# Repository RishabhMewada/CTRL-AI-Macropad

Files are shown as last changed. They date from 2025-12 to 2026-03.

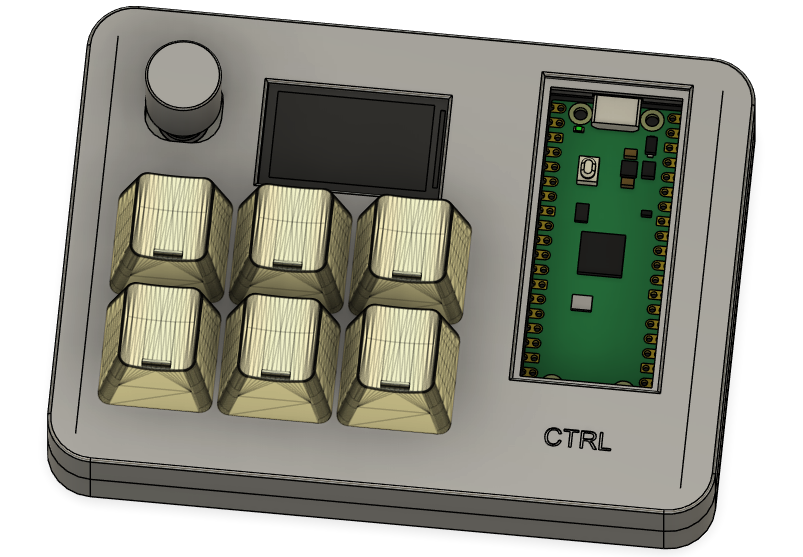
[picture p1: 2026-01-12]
Images/assembled-case.png

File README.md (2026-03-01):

# CTRL-AI-Macropad


## What is CTRL?
CTRL is a custom-built Human-Computer Interaction (HCI) Development Board designed for productivity tooling, embedded experimentation, wireless HID systems, and future AI-assisted workflows.

Originally developed as a programmable macropad, the project has evolved into a battery-powered, dual-transport embedded platform built around the Raspberry Pi Pico (RP2040), featuring modular firmware architecture and wireless expansion capabilities.CTRL is a custom-built Human-Computer Interaction (HCI) Development Board designed for productivity tooling, embedded experimentation, wireless HID systems, and future AI-assisted workflows.

Originally developed as a programmable macropad, the project has evolved into a battery-powered, dual-transport embedded platform built around the Raspberry Pi Pico (RP2040), featuring modular firmware architecture and wireless expansion capabilities.
<p align="center">
  

-------------------------------------------------------------------------------------------------
## Purpose 
The goal of this project was to design a fully custom embedded input system from scratch — including:

- PCB design
- Multi-MCU system architecture
- Power management circuitry
- Firmware modularization
- Custom enclosure
- This project focuses on understanding:
- Embedded system design
- Hardware-software co-design
- Power-aware firmware
- Multi-transport communication (USB + BLE)
- Expandable interaction hardware

The system is built with future extensibility in mind rather than being limited to fixed macro execution.

 <p align="center">
  
</p>

-------------------------------------------------------------------------------------------------
## Features

*Core Hardware*

- 6 Mechanical Keys (Cherry MX compatible)
- Rotary Encoder with integrated push switch
- 1.14″ IPS SPI Display (ST7789)
- Raspberry Pi Pico (RP2040)
- BLE Co-Processor (UART interface)
- Li-ion battery support
- On-board charging IC
- Software-controlled power system
- Fully custom 2-layer PCB
- Expansion GPIO header
- SWD debug header
-------------------------------------------------------------------------------------------------
## Transport & Connectivity

- USB HID (via Raspberry Pi Pico)
- Bluetooth HID (via BLE co-processor)
- UART-based inter-MCU communication
- I²C sensor bus (IMU connected with interrupt support)
-------------------------------------------------------------------------------------------------
## Hardware
The PCB is designed using KiCad (open-source) and Fusion 360.

Specifications

- 2-layer PCB
- Diode-protected key matrix
- SPI-connected IPS display
- I²C IMU (interrupt-driven)
- UART-connected BLE module
- Li-ion battery charging circuit (MCP73831)
- 3.3V LDO regulator (AP2112K)
- Single USB-C interface (handled by Pico only)

All PCB source files are available in `/hardware/kicad`.

<p align="center">
  
</p>

-------------------------------------------------------------------------------------------------

## Firmware
The firmware architecture has evolved from a monolithic USB HID mapping into a modular embedded system design.

**Architecture Overview**

*Subsystems include:*

- Input Processing Layer
- Power Management Layer
- Transport Abstraction Layer
- Communication Layer (UART BLE)
- Mode Manager

*Supported Features*

- Key matrix scanning
- Rotary encoder quadrature decoding
- USB HID output
- Bluetooth HID output
- 5-second long-press soft power
- Battery voltage monitoring
- Event-driven input routing

*Planned Enhancements*

- Dynamic key remapping
- On-device UI configuration
- BLE protocol expansion
- IMU gesture-based input
- Power optimization (sleep states)
- Desktop companion software

Firmware files are located in `/firmware`.

-------------------------------------------------------------------------------------------------
## Case
The enclosure is designed in Fusion 360 (personal use).
[STEP and source files are included in `/case`.]

**Dimensions:**
- Length: 11.8 cm
- Height: 6.3 cm
- Thickness: 1.5 cm

The enclosure is designed to be 3D printed.

~ **Recommended filament:** PLA  
PLA provides good dimensional accuracy, clean surface finish, and is easy to print, making it ideal for prototyping and desktop devices.

~ **Alternative:** PETG  
PETG can be used for improved durability and heat resistance, though it may require tuning for small cutouts.

[The enclosure is intended for indoor use and does not require high-temperature or impact-resistant materials.]

<p align="center">
  
</p>

-------------------------------------------------------------------------------------------------
## Images




-------------------------------------------------------------------------------------------------

## Future AI Integration (Planned)
CTRL is designed to support AI-assisted workflows through a host-based companion application.
AI processing will run on the host computer, while CTRL serves as:

~ low-latency physical interface
~ status display device
~ context-aware shortcut controller

The hardware architecture is transport-agnostic, enabling flexible integration with higher-level software systems.

-------------------------------------------------------------------------------------------------
## BOM
The complete bill of materials (BOM), including purchase links, is available in  
`/hardware/bom.csv`.

Manufacturing & sourcing:
- PCB fabrication: **JLCPCB**
- Components (India): **Robu.in**
- Enclosure: Online 3D printing services
  
-------------------------------------------------------------------------------------------------
## License
This project is open-source hardware and software and is released under the **MIT License**.

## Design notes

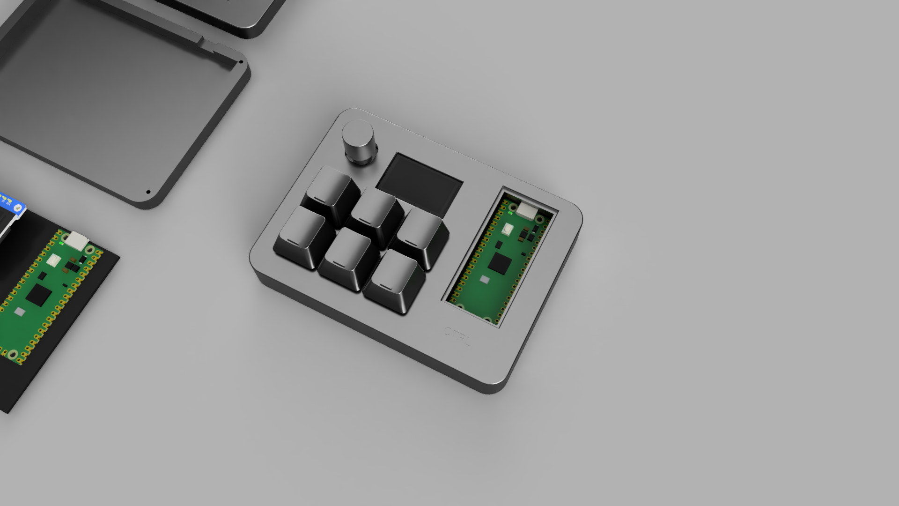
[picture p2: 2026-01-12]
Images/CTRL-AI-Macropad.f3d_2025-Dec-31_07-07-15PM-000_CustomizedView15149174459.png

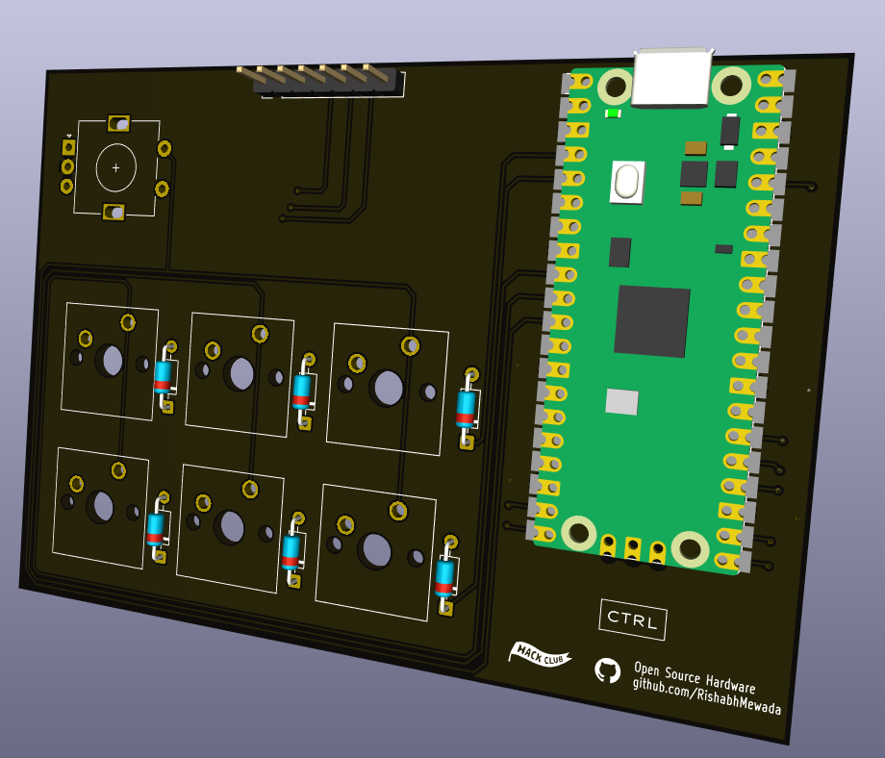
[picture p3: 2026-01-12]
Images/pcb-3d.png

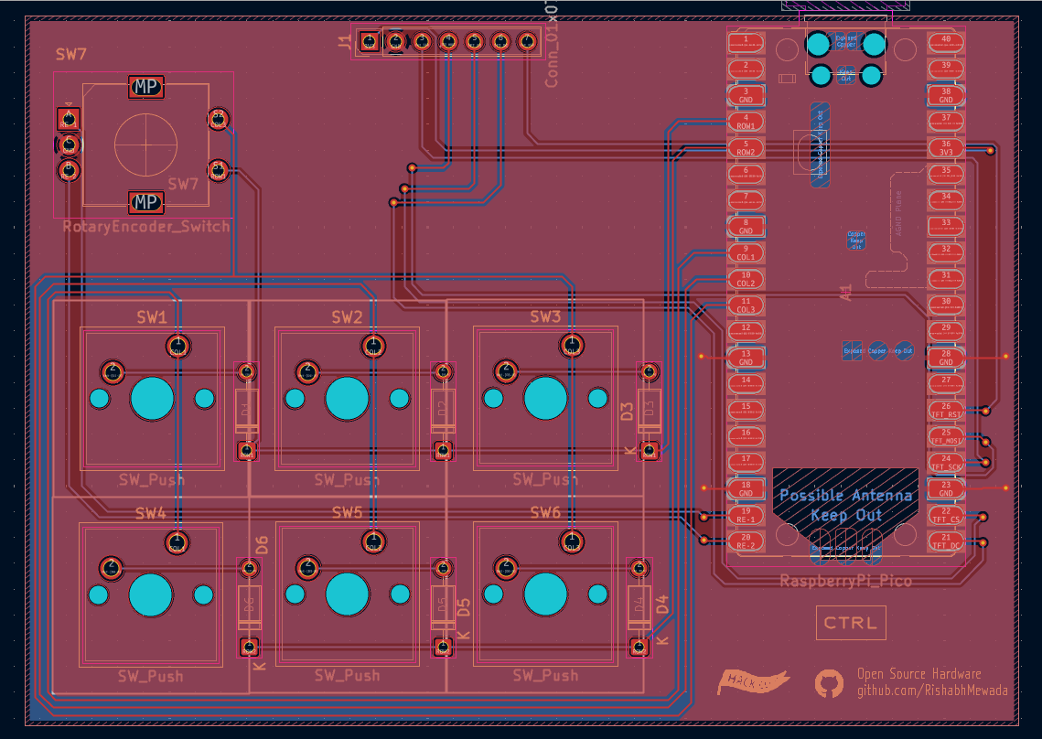
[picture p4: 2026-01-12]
Images/Pcb.png

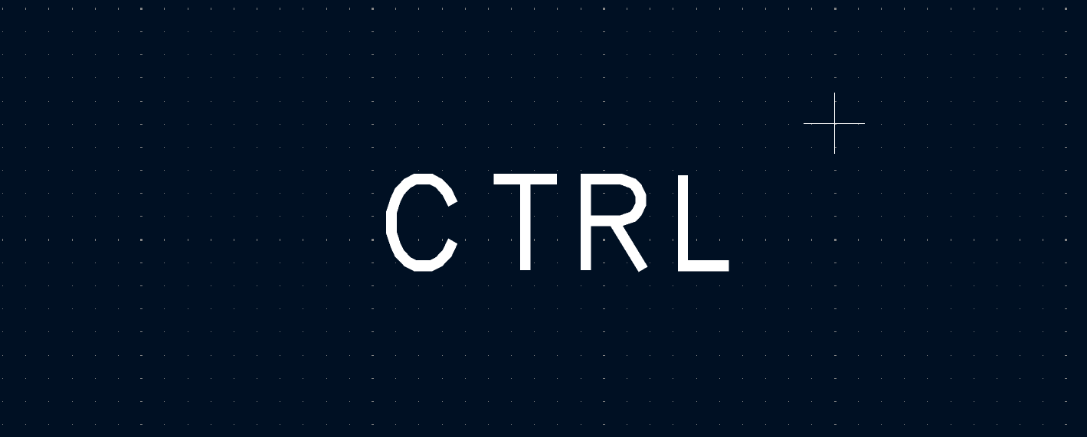
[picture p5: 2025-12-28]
Images/logo.png

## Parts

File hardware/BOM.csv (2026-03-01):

Item | Reference | Quantity | Part Name | Specification / Notes | Supplier | Link
1 | U1 | 1 | Raspberry Pi Pico (RP2040) | Microcontroller board | Robu.in | https://robu.in/product/raspberry-pi-pico/
2 | SW1-SW6 | 6 | Mechanical Key Switch | Cherry MX compatible (MX style) | Mckeys | https://meckeys.com/shop/accessories/keyboard-accessories/key-switches/cherry-mx-rgb-switch/
3 | D1-D7 | 7 | Signal Diode | 1N4148 DO-35 through-hole | Element14 india | https://in.element14.com/multicomp-pro/1n4148-do-35/small-signal-sw-diode-100v-do/dp/2675146
4 | SW7 | 1 | Rotary Encoder with Push Button | EC11 / EC12 style encoder | Flyrobo.in | https://www.flyrobo.in/ec11-rotary-encoder-with-switch-digital-potentiometer-20mm
5 | DS1 | 1 | IPS TFT Display | 1.14 inch 135x240 SPI IPS TFT | zbotic.in | https://zbotic.in/product/1-14-inch-135240-rgb-tft-ips-lcd-module-8pin-st7789-chip/
6 | J1 | 1 | Pin Header | 1x7 2.54mm Through-Hole | Amazon.in | https://www.amazon.in/7%C3%971-7Pin-Square-Straight-Header-Connector/dp/B0FFHLJHGR
7 | U2 | 1 | Bluetooth Module | MDBT50Q-1MV2 | Mouser Electronics | https://www.mouser.in/ProductDetail/Seeed-Studio/113990584?qs=0lSvoLzn4L92aqwOsif%2FOw%3D%3D
8 | BT1 | 1 | Li-Po Battery | 3.7 V Li-Po, 500–1000 mAh | Robu.in | https://robu.in/product/1500mah-pcm-protected-micro-li-po-battery/
9 | U3 | 1 | Battery Charging IC | MCP73831-2-OT (Li-Po charger) | Robu.in | https://robu.in/product/mcp73831t-2aci-ot-4-2v-500ma-single-cell-li-ion-li-polymer-battery-charge-management-controller-5-pin-sot-23-microchip-technology/
10 | J2 | 1 | Battery Connector | JST-PH 2-pin, 2.0 mm | Sunrom electronics | https://www.sunrom.com/p/2-pin-jst-ph-20mm-both-side-female-30cm
11 | J3 | 1 | External connector | 1×8 SWD Header, 2.54 mm | Amazon.in | https://www.amazon.in/8%C3%971-8Pin-Right-Angle-Header-Connector/dp/B0FFHNVV9Y
12 | U4 | 1 | MPU | MPU-6050 | Quartz components | https://quartzcomponents.com/products/mpu-6050-3-axis-gyro-accelerometer-ic-tdk-invensense-qfn-24-smd-package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
13 | PCB | 1 | Custom PCB | 2-layer PCB (KiCad) | JLCPCB | https://jlcpcb.com/
14 | CASE | 1 | 3D Printed Enclosure | Fusion 360 designed case | Local / Online 3D Print Service | N/A
15 | H1 | 1 | Header | 2 pin JST PH 2.0mm SMT Header Horizontal Right Angle Side Entry | Sunrom electronics | https://www.sunrom.com/p/2-pin-jst-ph-20mm-smt-header-horizontal-right-angle-side-entry
16 | U5 | 1 | Battery charger IC | AP2112K-3.3

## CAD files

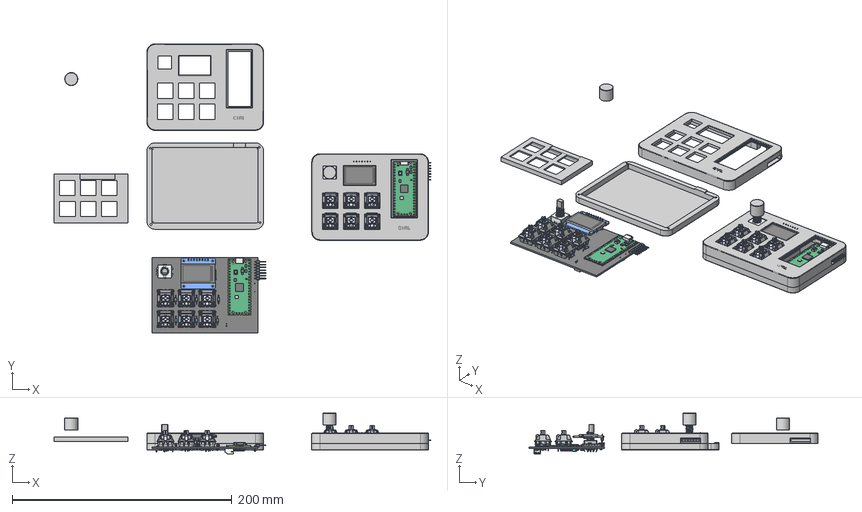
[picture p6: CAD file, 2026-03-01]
case/CTRL-AI-Macropad.f3d.step
343.0 x 263.2 x 37.2 mm
MX Öá °´¼ü¡ä_¨¹ ___¡§1 x 12
MX Öá ÖáÌå¨¢¨¬ _¡§¡é¡§__ x 12
MXÖá ÎÞÃ±LEDLEDLED x 12
MXÖá ÖáÌå µ×²¿ ¦Ì¡ Á2__Ä¬ÈÏ_¨¢2____¨¨_ x 12
Õë½Å___Ä¬ÈÏ__¨¨ _ x 12
Ðý×ª±àÂëÆ÷ x 2
no_8logo x 2
no_8logo--1 x 2
no_8logo--2 x 2
no_8logo--3 x 2
no_8logo--4 x 2
no_8logo--5 x 2
no_8logo--6 x 2
no_8logo--7 x 2
no_8logo--8 x 2
no_8logo--9 x 2
no_8logo--10 x 2
no_8logo--11 x 2
no_8logo--12 x 2
no_8logo--13 x 2
no_8logo--14 x 2
no_8logo--15 x 2
no_8logo--16 x 2
no_8logo--17 x 2
no_8logo--18 x 2
no_8logo--19 x 2
no_8logo--20 x 2
no_8logo--21 x 2
no_8logo--22 x 2
no_8logo--23 x 2
no_8logo--24 x 2
no_8logo--25 x 2
no_8logo--26 x 2
no_8logo--27 x 2
no_8logo--28 x 2
no_8logo--29 x 2
no_8logo--30 x 2
ER-TFT1.14-1 x 2
±³Ãæ x 2
Pin Header 8P x 2
Pin Header 8P--1 x 2
Pin Header 8P--2 x 2
Pin Header 8P--3 x 2
Pin Header 8P--4 x 2
Pin Header 8P--5 x 2
Pin Header 8P--6 x 2
Pin Header 8P--7 x 2
PCB°å x 2
D_DO-35_SOD27_P7.62mm_Horizontal x 14
PinHeader_1x07_P2.54mm_Vertical x 2
RaspberryPi_Pico_Module_KiCad x 2
PinHeader_1x07_P2.54mm_Horizontal x 2
SOT-23-5 x 4
Raytac_MDBT50Q x 2
JST_PH_S2B-PH-K_1x02_P2.00mm_Horizontal x 2
_autosave-Mechanical keyboard circuit_PCB x 2

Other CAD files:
case/CTRL-AI-Macropad.f3d.f3z

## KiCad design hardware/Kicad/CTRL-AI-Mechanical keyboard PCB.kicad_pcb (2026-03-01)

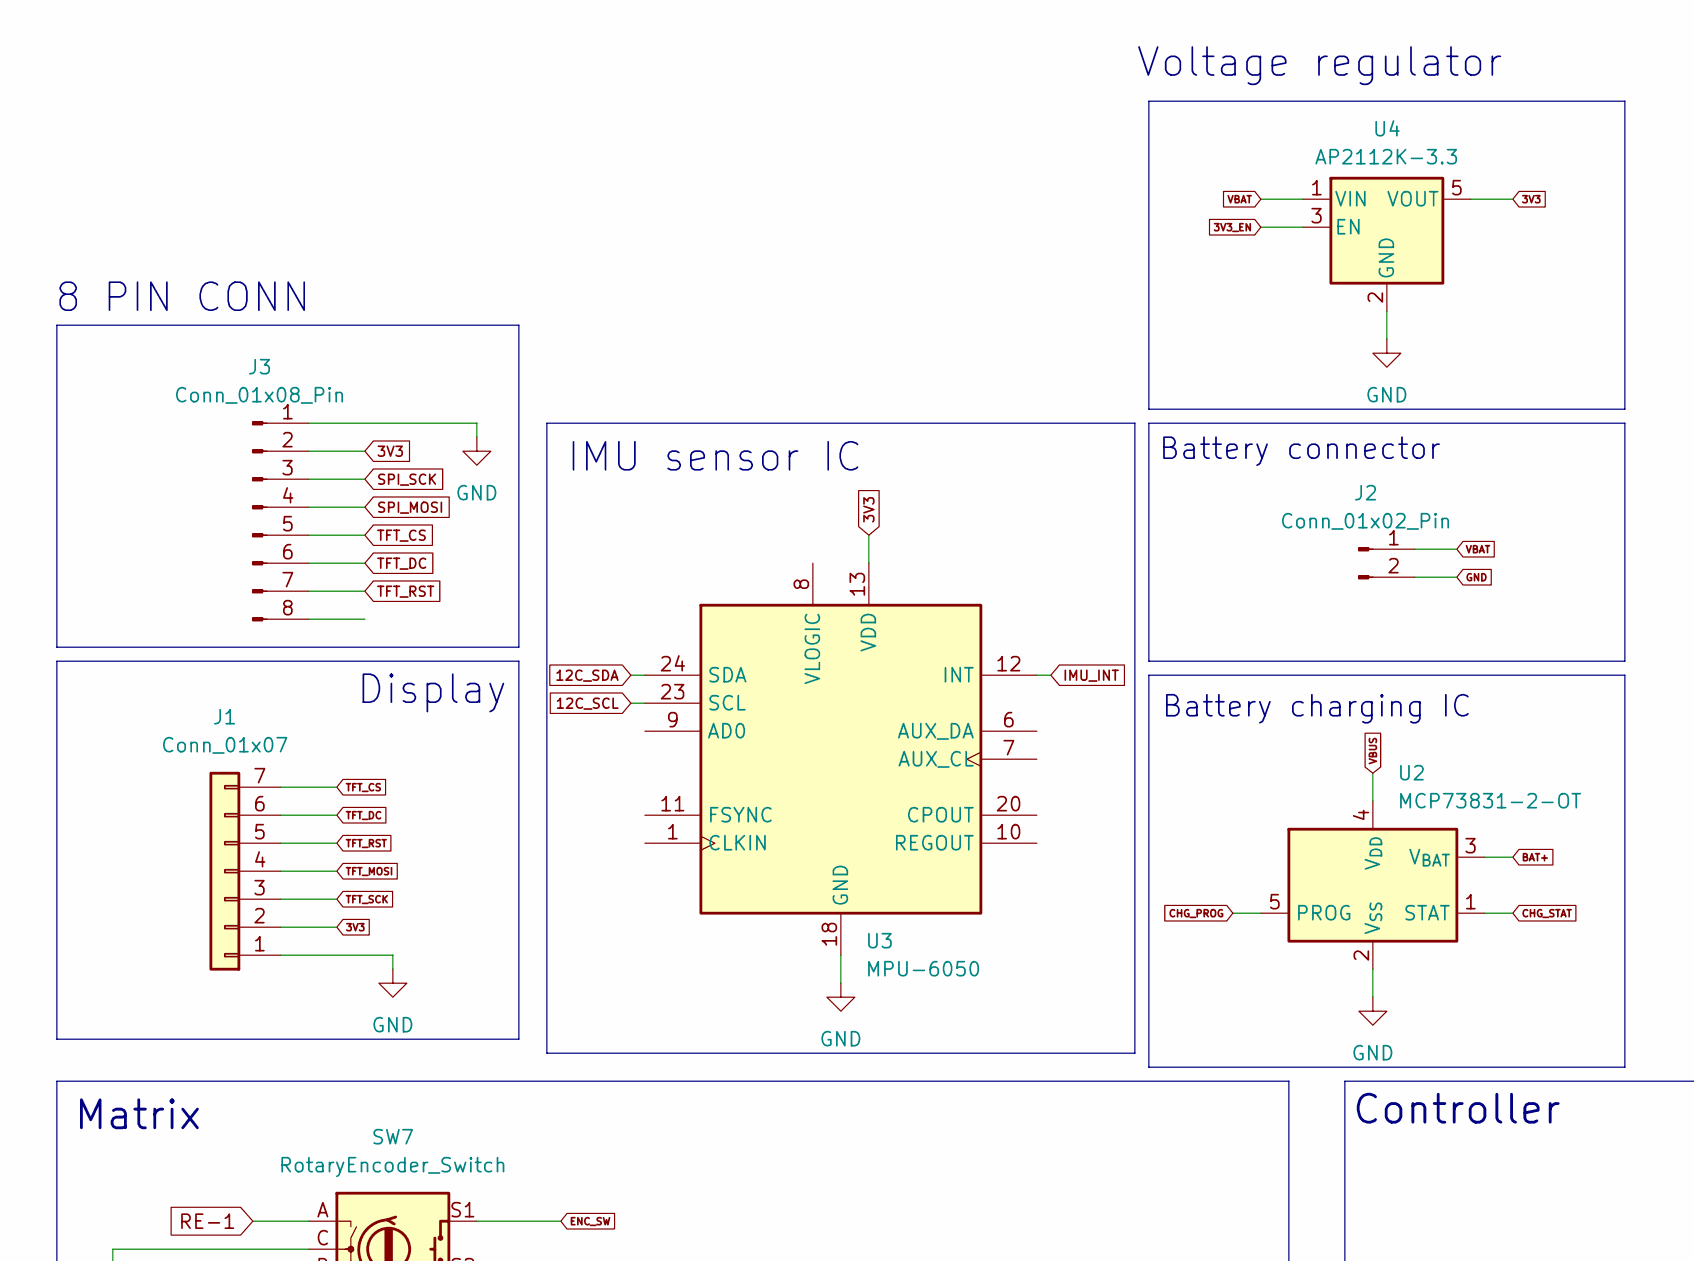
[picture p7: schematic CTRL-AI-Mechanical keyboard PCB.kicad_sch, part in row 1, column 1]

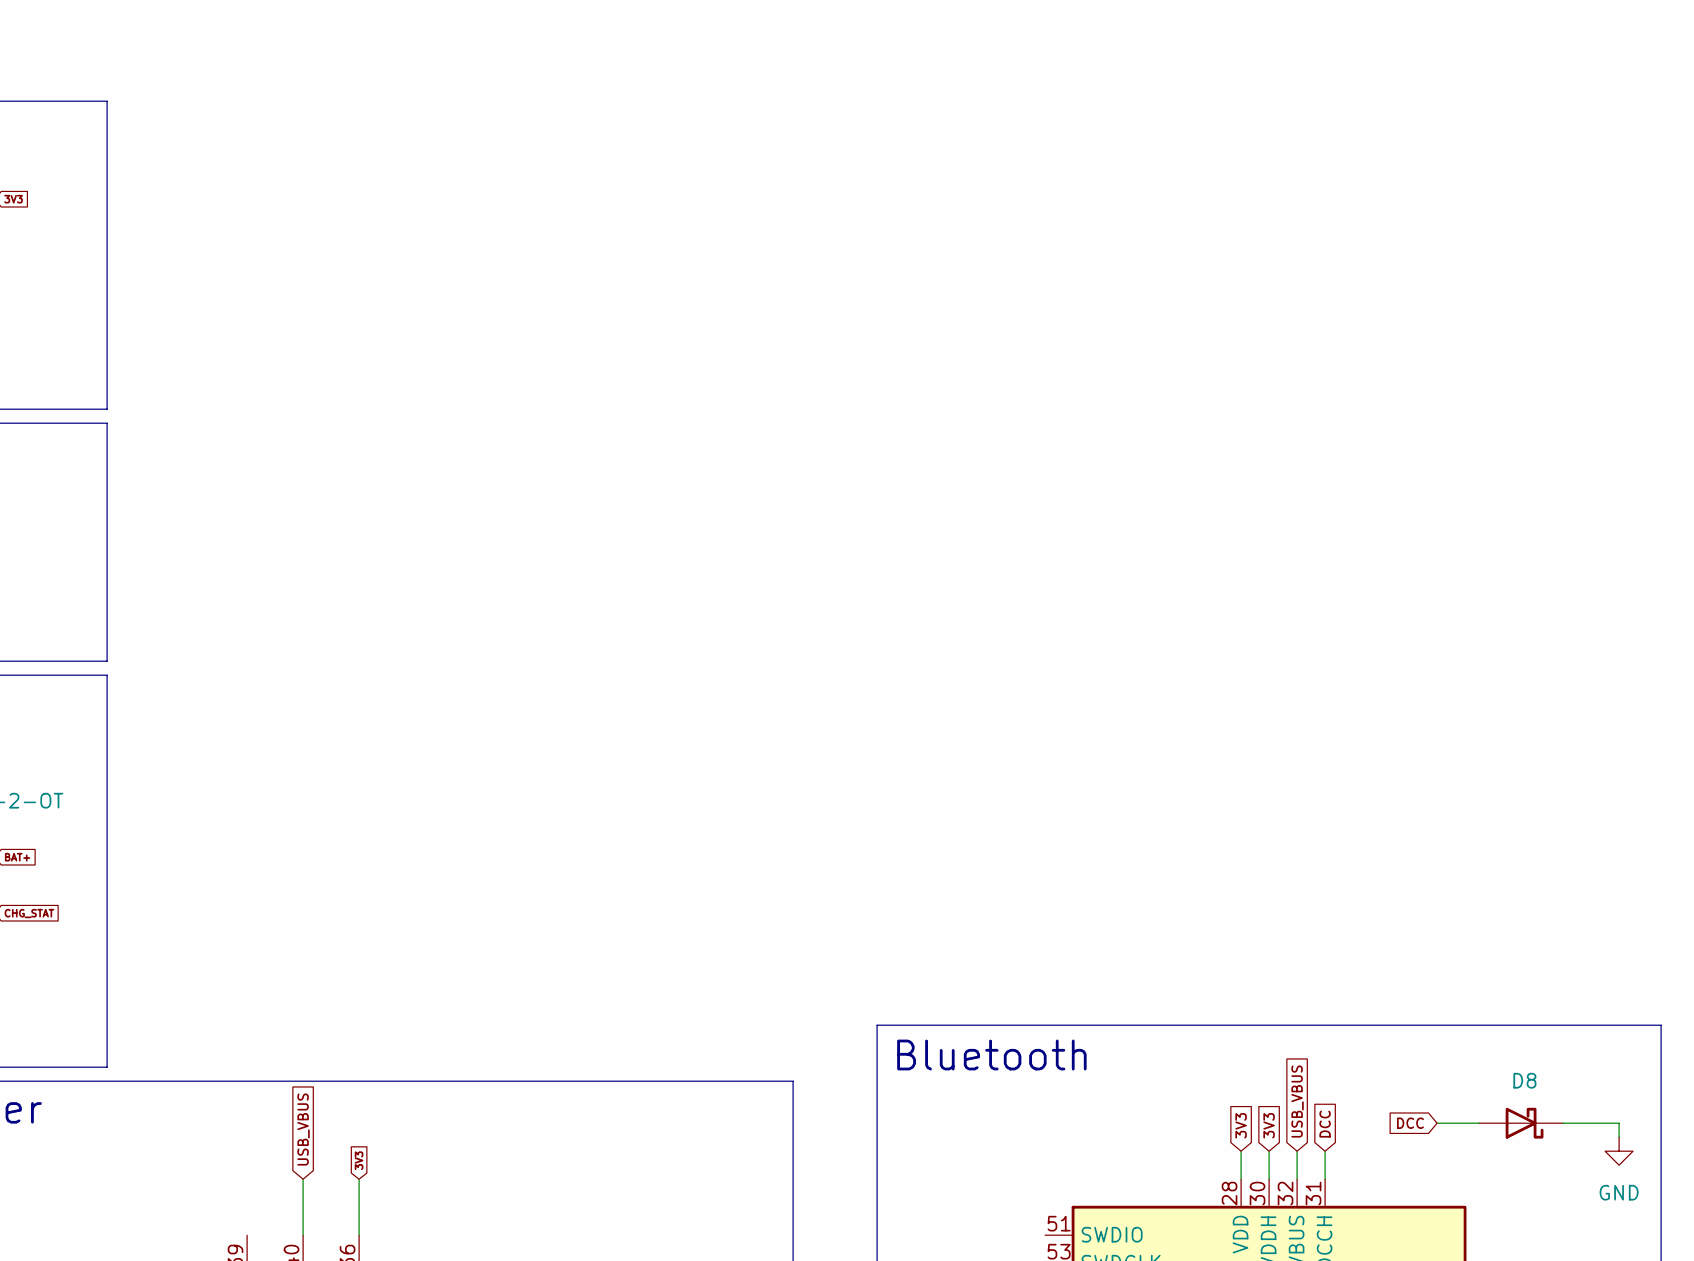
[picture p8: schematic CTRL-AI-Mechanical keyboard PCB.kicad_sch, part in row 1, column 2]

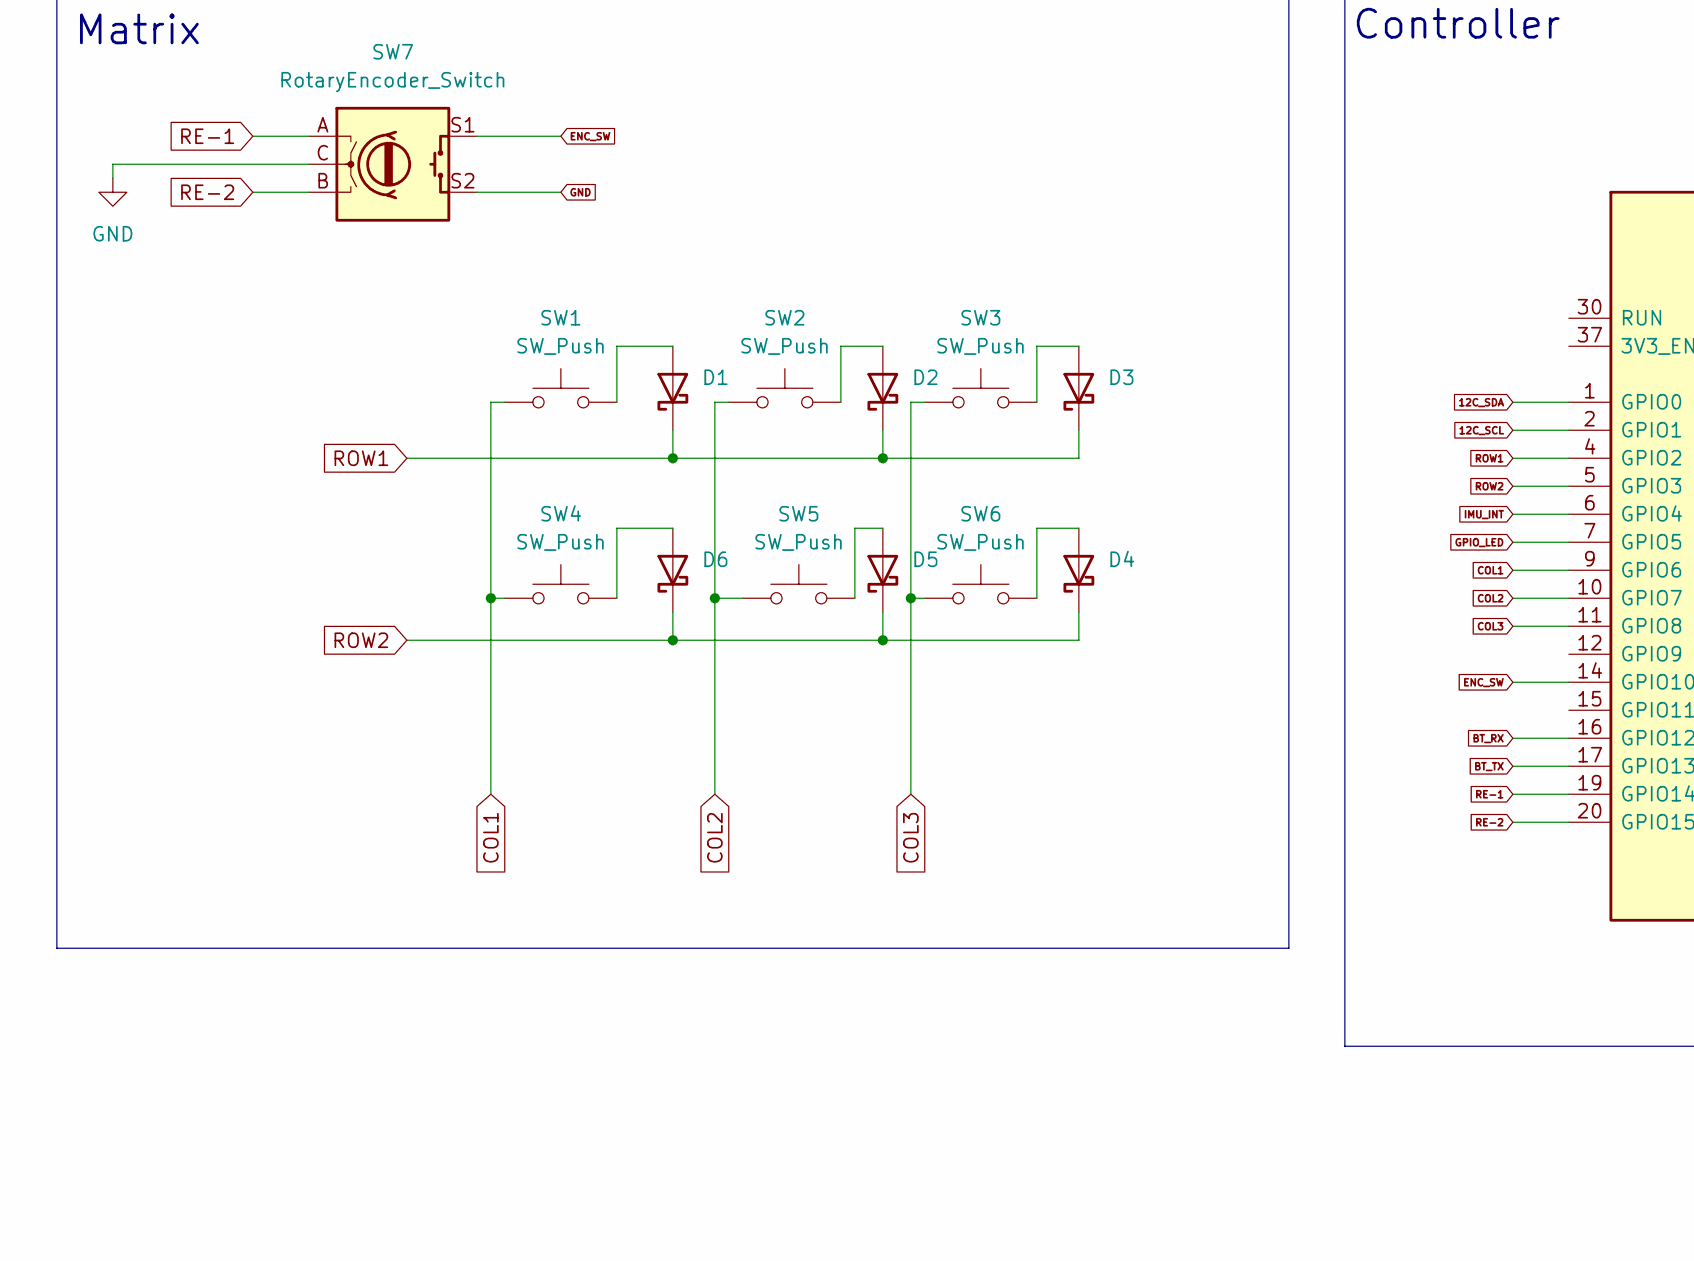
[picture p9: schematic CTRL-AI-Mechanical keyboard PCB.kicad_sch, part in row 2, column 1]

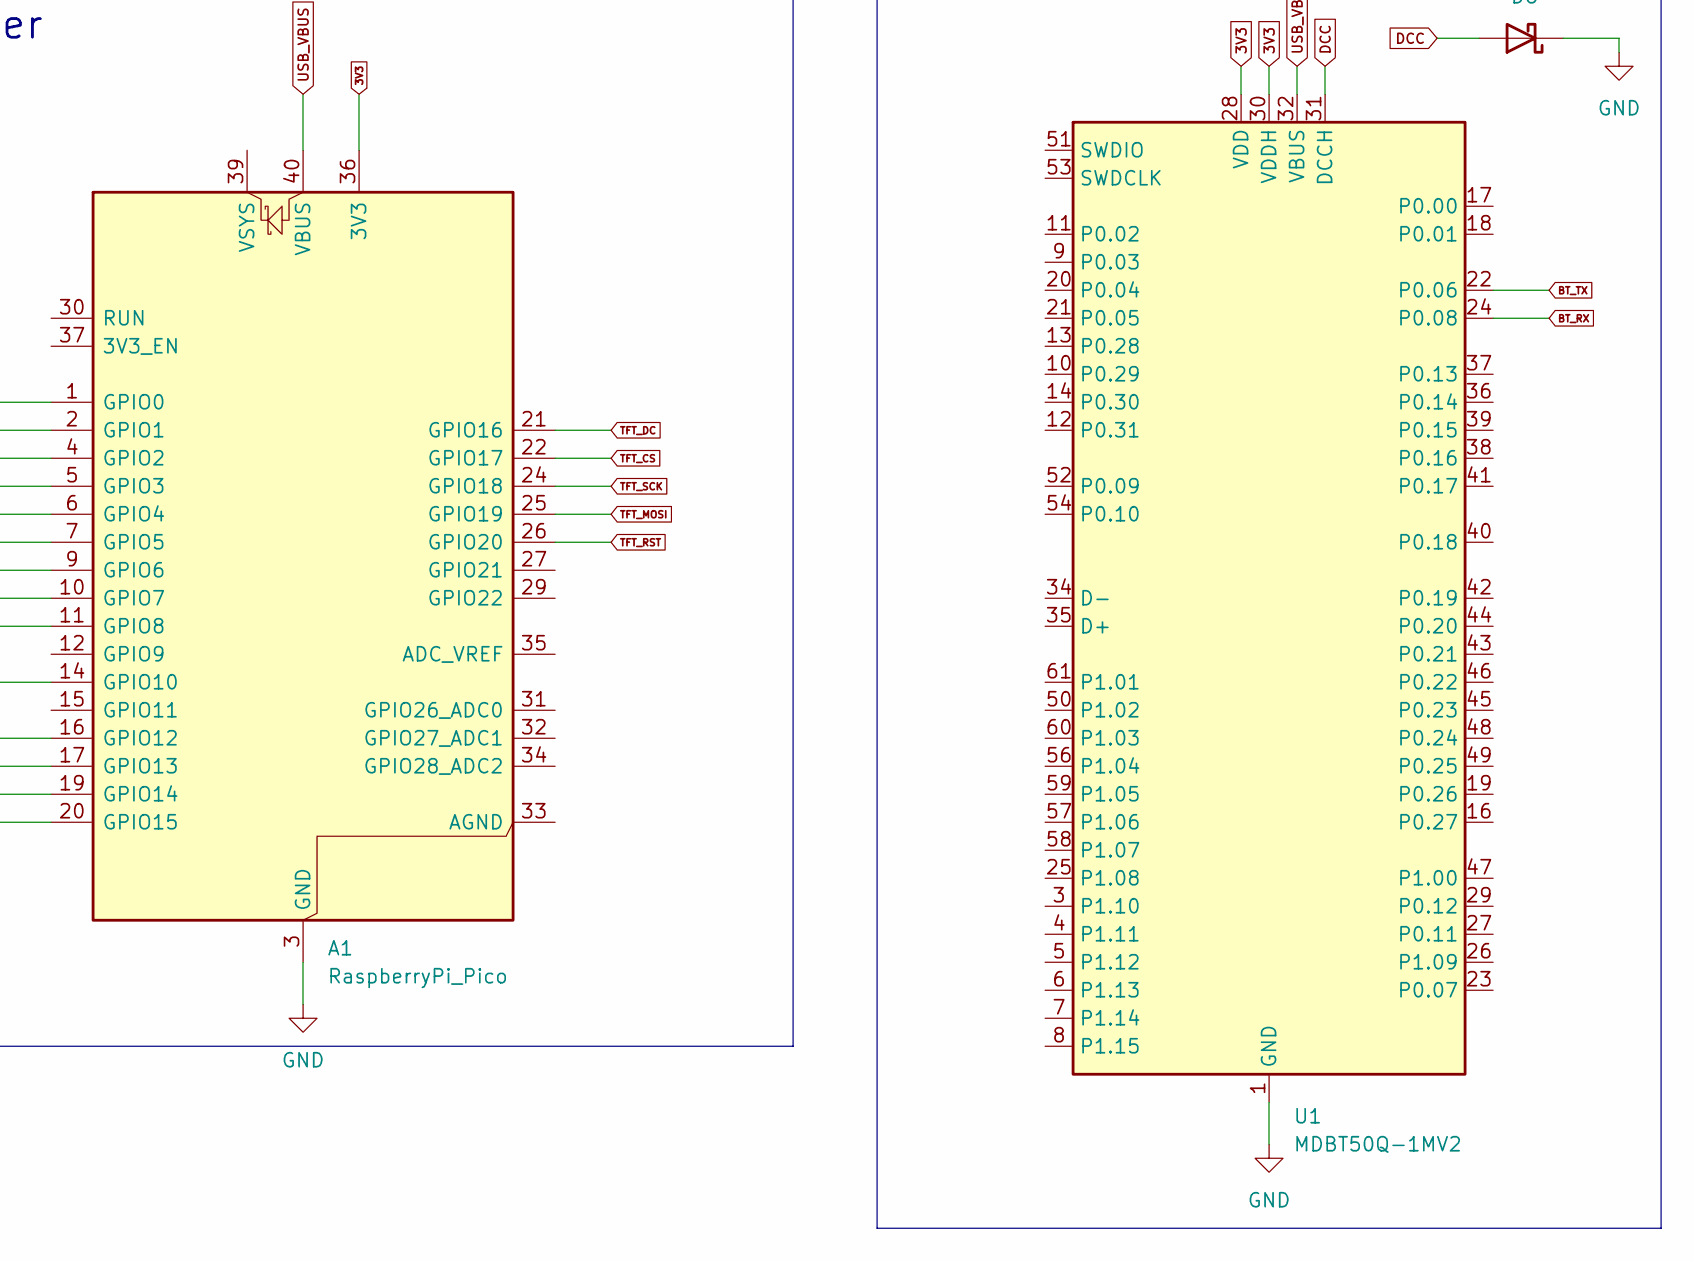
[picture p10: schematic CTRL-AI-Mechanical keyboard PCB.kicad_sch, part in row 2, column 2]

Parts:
A1: RaspberryPi_Pico; RaspberryPi_Pico_Common_Unspecified
D1, D2, D3, D4, D5, D6, D8: DSB5712; D_DO-35_SOD27_P7.62mm_Horizontal
J1: Conn_01x07; PinHeader_1x07_P2.54mm_Vertical
J2: Conn_01x02_Pin; JST_PH_S2B-PH-K_1x02_P2.00mm_Horizontal
J3: Conn_01x08_Pin; PinHeader_1x07_P2.54mm_Horizontal
SW1, SW2, SW3, SW4, SW5, SW6: SW_Push; SW_Cherry_MX_1.00u_PCB
SW7: RotaryEncoder_Switch; RotaryEncoder_Alps_EC11E-Switch_Vertical_H20mm
U1: MDBT50Q-1MV2; Raytac_MDBT50Q
U2: MCP73831-2-OT; SOT-23-5
U3: MPU-6050; InvenSense_QFN-24_4x4mm_P0.5mm
U4: AP2112K-3.3; SOT-23-5

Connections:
3V3: A1.36 (3V3), J1.2, J3.2, U1.28 (VDD), U1.30 (VDDH), U3.13 (VDD), U4.5 (VOUT)
3V3_EN: U4.3 (EN)
12C_SCL: A1.2 (GPIO1), U3.23 (SCL)
12C_SDA: A1.1 (GPIO0), U3.24 (SDA)
BAT+: U2.3 (V_{BAT})
BT_RX: A1.16 (GPIO12), U1.24 (P0.08)
BT_TX: A1.17 (GPIO13), U1.22 (P0.06)
CHG_PROG: U2.5 (PROG)
CHG_STAT: U2.1 (STAT)
COL1: A1.9 (GPIO6), SW1.1, SW4.1
COL2: A1.10 (GPIO7), SW2.1, SW5.1
COL3: A1.11 (GPIO8), SW3.1, SW6.1
DCC: D8.2 (A), U1.31 (DCCH)
ENC_SW: A1.14 (GPIO10), SW7.S1
GND: A1.3 (GND), A1.8 (GND), A1.13 (GND), A1.18 (GND), A1.23 (GND), A1.28 (GND), A1.38 (GND), D8.1 (K), J1.1, J2.2, J3.1, SW7.C, SW7.S2, U1.1 (GND), U1.2 (GND), U1.15 (GND), U1.33 (GND), U1.55 (GND), U2.2 (V_{SS}), U3.18 (GND), U4.2 (GND)
GPIO_LED: A1.7 (GPIO5)
IMU_INT: A1.6 (GPIO4), U3.12 (INT)
unnamed: D1.2 (A), SW1.2
unnamed: D2.2 (A), SW2.2
unnamed: D3.2 (A), SW3.2
unnamed: D4.2 (A), SW6.2
unnamed: D5.2 (A), SW5.2
unnamed: D6.2 (A), SW4.2
RE-1: A1.19 (GPIO14), SW7.A
RE-2: A1.20 (GPIO15), SW7.B
ROW1: A1.4 (GPIO2), D1.1 (K), D2.1 (K), D3.1 (K)
ROW2: A1.5 (GPIO3), D4.1 (K), D5.1 (K), D6.1 (K)
SPI_MOSI: J3.4
SPI_SCK: J3.3
TFT_CS: A1.22 (GPIO17), J1.7, J3.5
TFT_DC: A1.21 (GPIO16), J1.6, J3.6
TFT_MOSI: A1.25 (GPIO19), J1.4
TFT_RST: A1.26 (GPIO20), J1.5, J3.7
TFT_SCK: A1.24 (GPIO18), J1.3
USB_VBUS: A1.40 (VBUS), U1.32 (VBUS)
VBAT: J2.1, U4.1 (VIN)
VBUS: U2.4 (V_{DD})

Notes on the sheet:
Battery connector
Voltage regulator
Battery charging IC
Display
Bluetooth
Matrix
8 PIN CONN
Controller
IMU sensor IC

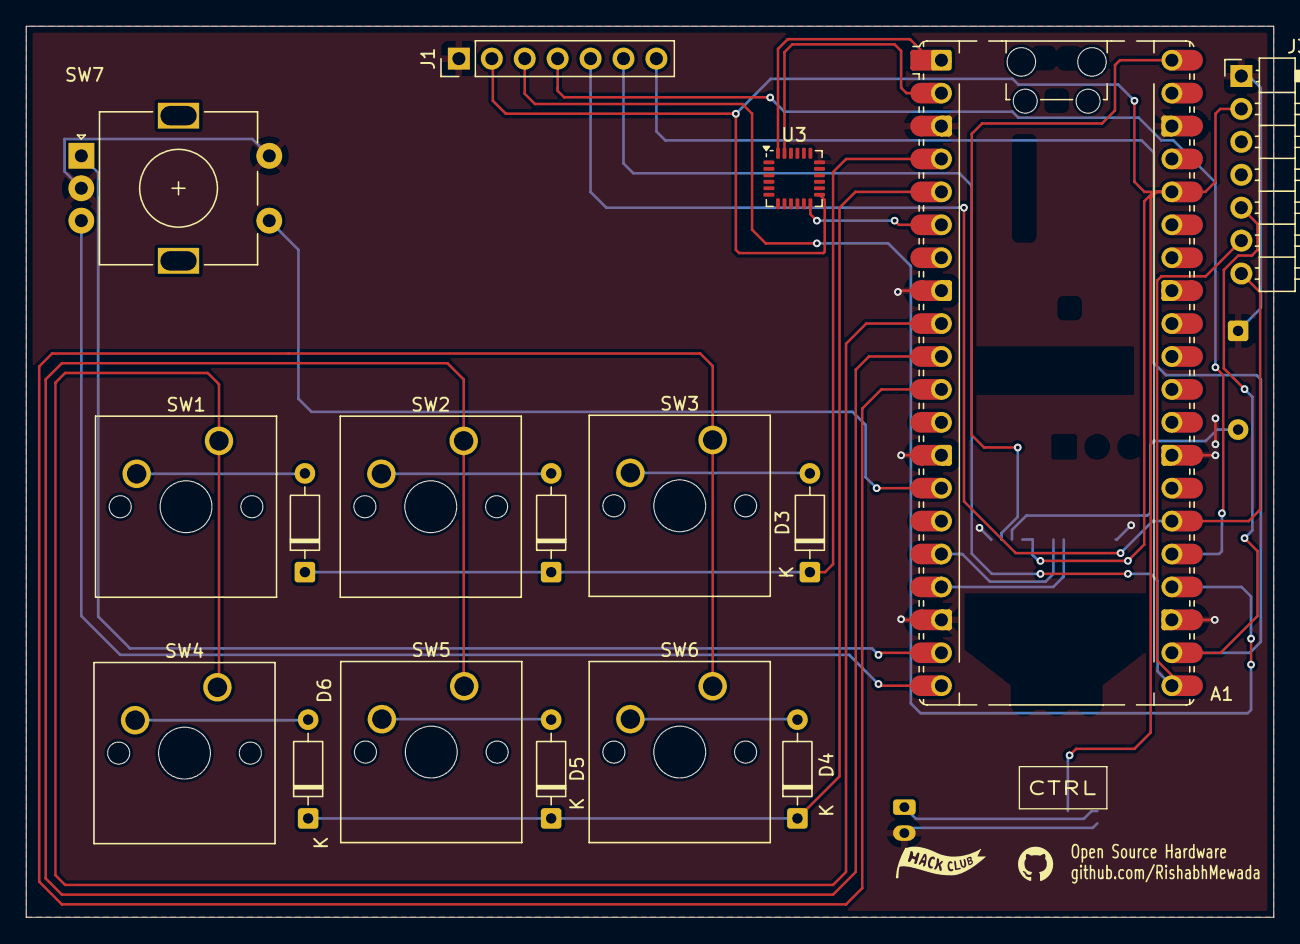
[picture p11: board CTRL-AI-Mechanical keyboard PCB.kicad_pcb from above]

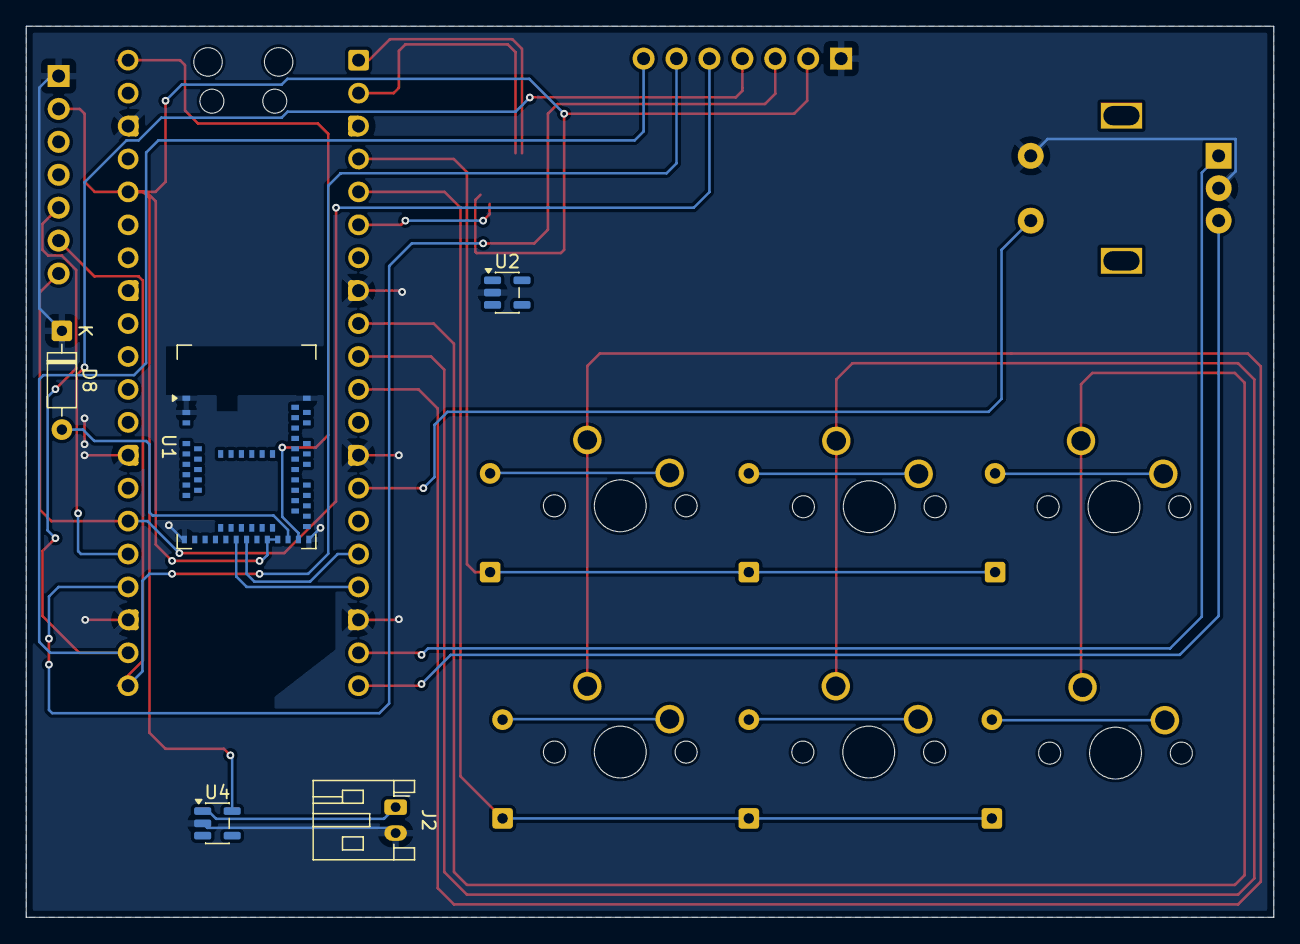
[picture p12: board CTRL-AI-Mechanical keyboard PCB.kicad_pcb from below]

Board: 2 copper layers, 96.2 x 68.8 mm, 22 parts (5 on the bottom side), 29 nets.

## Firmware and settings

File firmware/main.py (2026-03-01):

 # ================================
# CTRL Macro Pad Firmware v3.0
# AI-Ready Programmable Macro Pad
# NEW: Bluetooth, Battery Monitor, Power Management
# ================================

import board
import busio
import time
import digitalio
import analogio
from kmk.kmk_keyboard import KMKKeyboard
from kmk.scanners.keypad import MatrixScanner
from kmk.keys import KC
from kmk.modules.encoder import EncoderHandler
from kmk.modules.layers import Layers
from kmk.extensions.media_keys import MediaKeys

# ----------------
# Hardware Configuration
# ----------------
class Config:
    """Complete hardware configuration"""
    
    # Matrix Configuration (6 mechanical keys)
    ROW_PINS = (board.GP2, board.GP3)
    COL_PINS = (board.GP6, board.GP7, board.GP8)
    
    # Rotary Encoder with Push Switch
    ENCODER_A = board.GP14      # RE-1 (CLK)
    ENCODER_B = board.GP15      # RE-2 (DT)
    ENCODER_SW = board.GP14     # Switch (SW2 to GP14, SW1 to GND)
    
    # IPS Display (ST7789 - 135x240)
    DISPLAY_DC = board.GP16
    DISPLAY_CS = board.GP17
    DISPLAY_SCK = board.GP18
    DISPLAY_MOSI = board.GP19
    DISPLAY_RST = board.GP20
    
    # Battery Monitor (ADC)
    BATTERY_PIN = board.GP26    # ADC0 - Battery voltage divider
    
    # Power Management
    LONG_PRESS_MS = 5000        # 5 seconds for power toggle
    LOW_BATTERY_THRESHOLD = 3.3  # Volts
    CRITICAL_BATTERY_THRESHOLD = 3.0  # Volts
    
    # Bluetooth (Optional - if HC-05/HC-06 module added)
    # BT_TX = board.GP0  # UART TX (future expansion)
    # BT_RX = board.GP1  # UART RX (future expansion)
    
    NUM_LAYERS = 3
    DIODE_DIRECTION = "COL2ROW"

# ----------------
# Power Management System
# ----------------
class PowerManager:
    """
    Manages device power states and battery monitoring
    """
    
    def __init__(self):
        self.device_on = True
        self.battery_voltage = 0.0
        self.battery_percent = 100
        self.press_start = None
        self.in_sleep = False
        
        # Initialize battery ADC
        try:
            self.battery_adc = analogio.AnalogIn(Config.BATTERY_PIN)
            self.battery_enabled = True
            print("✓ Battery monitor enabled")
        except Exception as e:
            print(f"⚠ Battery monitor disabled: {e}")
            self.battery_enabled = False
    
    def read_battery(self):
        """Read battery voltage and calculate percentage"""
        if not self.battery_enabled:
            return 100
        
        try:
            # Read ADC value (0-65535)
            raw = self.battery_adc.value
            
            # Convert to voltage (3.3V reference, voltage divider x2)
            self.battery_voltage = (raw / 65535.0) * 3.3 * 2.0
            
            # Calculate percentage (3.0V = 0%, 4.2V = 100% for LiPo)
            if self.battery_voltage >= 4.2:
                self.battery_percent = 100
            elif self.battery_voltage <= 3.0:
                self.battery_percent = 0
            else:
                self.battery_percent = int(((self.battery_voltage - 3.0) / 1.2) * 100)
            
            return self.battery_percent
            
        except Exception as e:
            print(f"Battery read error: {e}")
            return 100
    
    def check_long_press(self, encoder_pressed):
        """
        Check for long press (5 seconds) to toggle power
        Returns True if power state should toggle
        """
        if encoder_pressed:
            if self.press_start is None:
                self.press_start = time.monotonic()
            
            elapsed = time.monotonic() - self.press_start
            
            if elapsed >= (Config.LONG_PRESS_MS / 1000.0):
                self.press_start = None
                return True
        else:
            self.press_start = None
        
        return False
    
    def enter_sleep(self):
        """Enter low-power sleep mode"""
        self.in_sleep = True
        self.device_on = False
        print("→ Entering sleep mode...")
        # Placeholder for actual sleep implementation
        # In CircuitPython, true deep sleep requires alarm module
    
    def wake_up(self):
        """Wake from sleep mode"""
        self.in_sleep = False
        self.device_on = True
        print("→ Waking up...")
    
    def get_battery_status(self):
        """Get battery status string"""
        if not self.battery_enabled:
            return "USB"
        
        if self.battery_voltage < Config.CRITICAL_BATTERY_THRESHOLD:
            return "CRITICAL"
        elif self.battery_voltage < Config.LOW_BATTERY_THRESHOLD:
            return "LOW"
        else:
            return f"{self.battery_percent}%"

# Initialize power manager
power = PowerManager()

# ----------------
# Bluetooth Manager (Future Expansion)
# ----------------
class BluetoothManager:
    """
    Bluetooth HID support via HC-05/HC-06 module
    Currently placeholder for future hardware expansion
    """
    
    def __init__(self):
        self.enabled = False
        self.connected = False
        self.mode = "USB"  # "USB" or "BLUETOOTH"
    
    def init_uart(self):
        """Initialize UART for Bluetooth module"""
        # Future: Initialize UART on GP0/GP1
        # self.uart = busio.UART(board.GP0, board.GP1, baudrate=115200)
        pass
    
    def send_key_event(self, key_code, pressed):
        """Send key event over Bluetooth"""
        if not self.enabled or not self.connected:
            return
        # Future: Send HID packets over UART
        pass
    
    def send_encoder_event(self, direction):
        """Send encoder rotation over Bluetooth"""
        if not self.enabled or not self.connected:
            return
        # Future: Send encoder data
        pass
    
    def poll(self):
        """Check for incoming Bluetooth messages"""
        if not self.enabled:
            return
        # Future: Read UART data
        pass
    
    def toggle_mode(self):
        """Switch between USB and Bluetooth modes"""
        if not self.enabled:
            return
        
        self.mode = "BLUETOOTH" if self.mode == "USB" else "USB"
        print(f"→ Mode: {self.mode}")
        return self.mode

# Initialize Bluetooth manager
bluetooth = BluetoothManager()

# ----------------
# Keyboard Setup
# ----------------
keyboard = KMKKeyboard()

# Initialize modules
layers_module = Layers()
encoder_module = EncoderHandler()
media_keys = MediaKeys()

# Register modules and extensions
keyboard.modules = [layers_module, encoder_module]
keyboard.extensions = [media_keys]

# ----------------
# Matrix Scanner
# ----------------
keyboard.matrix = MatrixScanner(
    row_pins=Config.ROW_PINS,
    col_pins=Config.COL_PINS,
    columns_to_anodes=Config.DIODE_DIRECTION,
    interval=0.02,
    max_events=64
)

# ----------------
# Rotary Encoder
# ----------------
encoder_module.pins = (
    (Config.ENCODER_A, Config.ENCODER_B, Config.ENCODER_SW),
)

# ----------------
# Custom Macros
# ----------------

# Productivity
COPY = KC.LCTL(KC.C)
PASTE = KC.LCTL(KC.V)
CUT = KC.LCTL(KC.X)
UNDO = KC.LCTL(KC.Z)
REDO = KC.LCTL(KC.Y)
SAVE = KC.LCTL(KC.S)
SELECT_ALL = KC.LCTL(KC.A)
FIND = KC.LCTL(KC.F)

# Browser/Tabs
NEW_TAB = KC.LCTL(KC.T)
CLOSE_TAB = KC.LCTL(KC.W)
REOPEN_TAB = KC.LCTL(KC.LSFT(KC.T))
REFRESH = KC.LCTL(KC.R)

# Developer
COMMENT_LINE = KC.LCTL(KC.SLASH)
FORMAT_DOC = KC.LSFT(KC.LALT(KC.F))
TERMINAL = KC.LCTL(KC.GRAVE)
COMMAND_PALETTE = KC.LCTL(KC.LSFT(KC.P))

# Screenshot
SCREENSHOT = KC.LGUI(KC.LSFT(KC.S))

# ----------------
# Encoder Behavior
# ----------------
encoder_module.map = [
    # Layer 0: Volume + Mute
    ((KC.VOLU, KC.VOLD, KC.MUTE),),
    
    # Layer 1: Scroll + Enter
    ((KC.RIGHT, KC.LEFT, KC.ENTER),),
    
    # Layer 2: Zoom + Reset
    ((KC.LCTL(KC.EQUAL), KC.LCTL(KC.MINUS), KC.LCTL(KC.N0)),),
]

# ----------------
# Keymap
# ----------------
keyboard.keymap = [
    # Layer 0 — Productivity
    [
        COPY,           # SW1
        PASTE,          # SW2
        CUT,            # SW3
        UNDO,           # SW4
        SAVE,           # SW5
        KC.MO(1),       # SW6 → Layer 1
    ],
    
    # Layer 1 — Media & Navigation
    [
        KC.MPLY,        # SW1: Play/Pause
        KC.MNXT,        # SW2: Next
        KC.MPRV,        # SW3: Previous
        KC.HOME,        # SW4: Home
        KC.END,         # SW5: End
        KC.MO(2),       # SW6 → Layer 2
    ],
    
    # Layer 2 — Developer Tools
    [
        NEW_TAB,        # SW1
        CLOSE_TAB,      # SW2
        COMMAND_PALETTE,# SW3
        COMMENT_LINE,   # SW4
        TERMINAL,       # SW5
        KC.TO(0),       # SW6 → Layer 0
    ],
]

# ----------------
# Display Manager
# ----------------
class DisplayManager:
    """Enhanced display with battery and status info"""
    
    def __init__(self):
        self.enabled = False
        self.display = None
        self.current_layer = 0
        self.last_battery_check = 0
        self.init_display()
    
    def init_display(self):
        """Initialize SPI display"""
        try:
            import displayio
            import adafruit_st7789
            from adafruit_display_text import label
            import terminalio
            
            displayio.release_displays()
            
            spi = busio.SPI(
                clock=Config.DISPLAY_SCK,
                MOSI=Config.DISPLAY_MOSI
            )
            
            display_bus = displayio.FourWire(
                spi,
                command=Config.DISPLAY_DC,
                chip_select=Config.DISPLAY_CS,
                reset=Config.DISPLAY_RST
            )
            
            self.display = adafruit_st7789.ST7789(
                display_bus,
                width=135,
                height=240,
                rotation=90,
                rowstart=40,
                colstart=53
            )
            
            self.enabled = True
            self.show_startup()
            print("✓ Display initialized")
            
        except ImportError:
            print("⚠ Display libraries missing")
            self.enabled = False
        except Exception as e:
            print(f"✗ Display init failed: {e}")
            self.enabled = False
    
    def show_startup(self):
        """Enhanced startup screen with battery info"""
        if not self.enabled:
            return
        
        try:
            import displayio
            from adafruit_display_text import label
            import terminalio
            
            splash = displayio.Group()
            
            # Title
            title = label.Label(
                terminalio.FONT,
                text="CTRL",
                color=0x00FF00,
                scale=3,
                x=80,
                y=20
            )
            
            # Version
            version = label.Label(
                terminalio.FONT,
                text="v3.0 PRO",
                color=0xFFFFFF,
                scale=1,
                x=85,
                y=50
            )
            
            # Battery status
            battery_status = power.get_battery_status()
            battery_color = 0x00FF00 if power.battery_percent > 50 else (
                0xFFFF00 if power.battery_percent > 20 else 0xFF0000
            )
            
            battery = label.Label(
                terminalio.FONT,
                text=f"Battery: {battery_status}",
                color=battery_color,
                scale=1,
                x=60,
                y=75
            )
            
            # Mode indicator
            mode = label.Label(
                terminalio.FONT,
                text=f"Mode: {bluetooth.mode}",
                color=0x00FFFF,
                scale=1,
                x=70,
                y=95
            )
            
            # Status
            status = label.Label(
                terminalio.FONT,
                text="READY",
                color=0x00FFFF,
                scale=2,
                x=80,
                y=115
            )
            
            splash.append(title)
            splash.append(version)
            splash.append(battery)
            splash.append(mode)
            splash.append(status)
            
            self.display.show(splash)
            
        except Exception as e:
            print(f"Startup display error: {e}")
    
    def show_layer(self, layer_num):
        """Display layer with battery indicator"""
        if not self.enabled:
            return
        
        self.current_layer = layer_num
        layer_names = ["PRODUCTIVITY", "MEDIA", "DEVELOPER"]
        layer_colors = [0x00FF00, 0xFF00FF, 0x00FFFF]
        
        if 0 <= layer_num < len(layer_names):
            try:
                import displayio
                from adafruit_display_text import label
                import terminalio
                
                splash = displayio.Group()
                
                # Battery indicator (top right)
                battery_status = power.get_battery_status()
                battery_color = 0x00FF00 if power.battery_percent > 50 else (
                    0xFFFF00 if power.battery_percent > 20 else 0xFF0000
                )
                
                battery_label = label.Label(
                    terminalio.FONT,
                    text=battery_status,
                    color=battery_color,
                    scale=1,
                    x=190,
                    y=10
                )
                
                # Layer number
                layer_label = label.Label(
                    terminalio.FONT,
                    text=f"LAYER {layer_num}",
                    color=0xFFFFFF,
                    scale=2,
                    x=60,
                    y=40
                )
                
                # Layer name
                name_label = label.Label(
                    terminalio.FONT,
                    text=layer_names[layer_num],
                    color=layer_colors[layer_num],
                    scale=2,
                    x=20,
                    y=80
                )
                
                splash.append(battery_label)
                splash.append(layer_label)
                splash.append(name_label)
                self.display.show(splash)
                
            except Exception as e:
                print(f"Layer display error: {e}")
    
    def show_low_battery_warning(self):
        """Show critical battery warning"""
        if not self.enabled:
            return
        
        try:
            import displayio
            from adafruit_display_text import label
            import terminalio
            
            splash = displayio.Group()
            
            warning = label.Label(
                terminalio.FONT,
                text="LOW BATTERY!",
                color=0xFF0000,
                scale=2,
                x=40,
                y=60
            )
            
            voltage = label.Label(
                terminalio.FONT,
                text=f"{power.battery_voltage:.2f}V",
                color=0xFFFF00,
                scale=2,
                x=80,
                y=90
            )
            
            splash.append(warning)
            splash.append(voltage)
            self.display.show(splash)
            
        except Exception as e:
            print(f"Warning display error: {e}")
    
    def update_battery_indicator(self):
        """Periodically update battery status"""
        current_time = time.monotonic()
        if current_time - self.last_battery_check > 30:  # Update every 30 seconds
            self.last_battery_check = current_time
            power.read_battery()
            
            if power.battery_voltage < Config.CRITICAL_BATTERY_THRESHOLD:
                self.show_low_battery_warning()

# Initialize display
display = DisplayManager()

# ----------------
# AI Integration
# ----------------
class AIInterface:
    """Enhanced AI interface with battery and mode awareness"""
    
    def __init__(self):
        self.context = "default"
        self.enabled = False
        self.serial = None
    
    def init_serial(self):
        """Initialize USB serial"""
        try:
            import usb_cdc
            self.serial = usb_cdc.data
            if self.serial:
                self.enabled = True
                print("✓ AI serial ready")
        except Exception as e:
            print(f"✗ AI init failed: {e}")
    
    def send_telemetry(self):
        """Send device telemetry to host"""
        if not self.enabled or not self.serial:
            return
        
        try:
            import json
            data = json.dumps({
                "type": "telemetry",
                "battery": power.battery_percent,
                "voltage": power.battery_voltage,
                "mode": bluetooth.mode,
                "layer": display.current_layer,
                "timestamp": time.monotonic()
            })
            self.serial.write((data + "\n").encode('utf-8'))
        except Exception as e:
            print(f"Telemetry error: {e}")
    
    def send_event(self, event_type, data):
        """Send event to host"""
        if not self.enabled or not self.serial:
            return
        
        try:
            import json
            message = json.dumps({
                "type": event_type,
                "data": data,
                "timestamp": time.monotonic()
            })
            self.serial.write((message + "\n").encode('utf-8'))
        except Exception as e:
            print(f"Event send error: {e}")

# Initialize AI interface
ai = AIInterface()
# ai.init_serial()  # Uncomment to enable

# ----------------
# Event Handlers
# ----------------

# Track encoder state for long press detection
encoder_pressed = False
last_telemetry = 0

def custom_process_key(key, is_pressed, int_coord):
    """Enhanced key handler with power management"""
    global encoder_pressed
    
    # Check if this is encoder button
    if hasattr(key, 'code') and key.code == Config.ENCODER_SW:
        encoder_pressed = is_pressed
        
        # Check for long press power toggle
        if power.check_long_press(encoder_pressed):
            if power.device_on:
                power.enter_sleep()
                display.show_low_battery_warning()  # Repurpose as sleep indicator
            else:
                power.wake_up()
                display.show_startup()
            return
    
    # Don't process keys if device is off
    if not power.device_on:
        return
    
    # Send to Bluetooth if in BT mode
    if bluetooth.mode == "BLUETOOTH" and is_pressed:
        bluetooth.send_key_event(key, is_pressed)
    
    # Send telemetry
    ai.send_event("key_press", {
        "key": str(key),
        "pressed": is_pressed,
        "position": int_coord
    })

# Layer change handler
def on_layer_change(layer):
    """Handle layer changes"""
    display.show_layer(layer)
    ai.send_event("layer_change", {"layer": layer})

# ----------------
# Main Loop Enhancement
# ----------------
def background_tasks():
    """Periodic background tasks"""
    global last_telemetry
    
    current_time = time.monotonic()
    
    # Update battery every 30 seconds
    if current_time - last_telemetry > 30:
        last_telemetry = current_time
        power.read_battery()
        display.update_battery_indicator()
        ai.send_telemetry()
    
    # Poll Bluetooth
    bluetooth.poll()
    
    # Check for critical battery
    if power.battery_voltage < Config.CRITICAL_BATTERY_THRESHOLD:
        print("⚠ CRITICAL BATTERY - Entering sleep mode")
        power.enter_sleep()

# Hook background tasks into KMK
keyboard.before_matrix_scan = background_tasks

# ----------------
# Startup
# ----------------
print("")
print("=" * 60)
print("   CTRL MACRO PAD v3.0 PRO")
print("   AI-Ready | Battery Powered | Bluetooth Ready")
print("=" * 60)
print("")
print("HARDWARE:")
print(f"  Matrix: 2x3 (6 keys)")
print(f"  Encoder: GP{Config.ENCODER_A.id}, GP{Config.ENCODER_B.id} + Switch")
print(f"  Display: 135x240 IPS {'✓' if display.enabled else '✗'}")
print(f"  Battery: {power.get_battery_status()} ({power.battery_voltage:.2f}V)")
print("")
print("FEATURES:")
print(f"  Layers: {Config.NUM_LAYERS}")
print(f"  Mode: {bluetooth.mode}")
print(f"  AI: {'✓ Ready' if ai.enabled else '○ Available'}")
print(f"  Power: Hold encoder {Config.LONG_PRESS_MS/1000:.0f}s to toggle")
print("")
print("=" * 60)
print("✓ All systems operational")
print("=" * 60)
print("")

# ----------------
# Start
# ----------------
if __name__ == '__main__':
    keyboard.go()
